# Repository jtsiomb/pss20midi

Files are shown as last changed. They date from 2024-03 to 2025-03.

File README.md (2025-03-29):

YAMAHA PSS-20 MIDI conversion
=============================

About
-----
This is a replacement board for the YAMAHA PSS-20 vintage toy keyboard, which
converts it into a polyphonic MIDI keyboard.

License
-------
Copyright (C) 2024 John Tsiombikas <nuclear@mutantstargoat.com>,
                   Eleni-Maria Stea <elene.mst@gmail.com>

All parts of this project are Free Software/Hardware. Feel free to use, modify
and/or redistribute under the terms of the GNU General Public License v3, or at
your option any later version published by the Free Software Foundation. See
COPYING for details.

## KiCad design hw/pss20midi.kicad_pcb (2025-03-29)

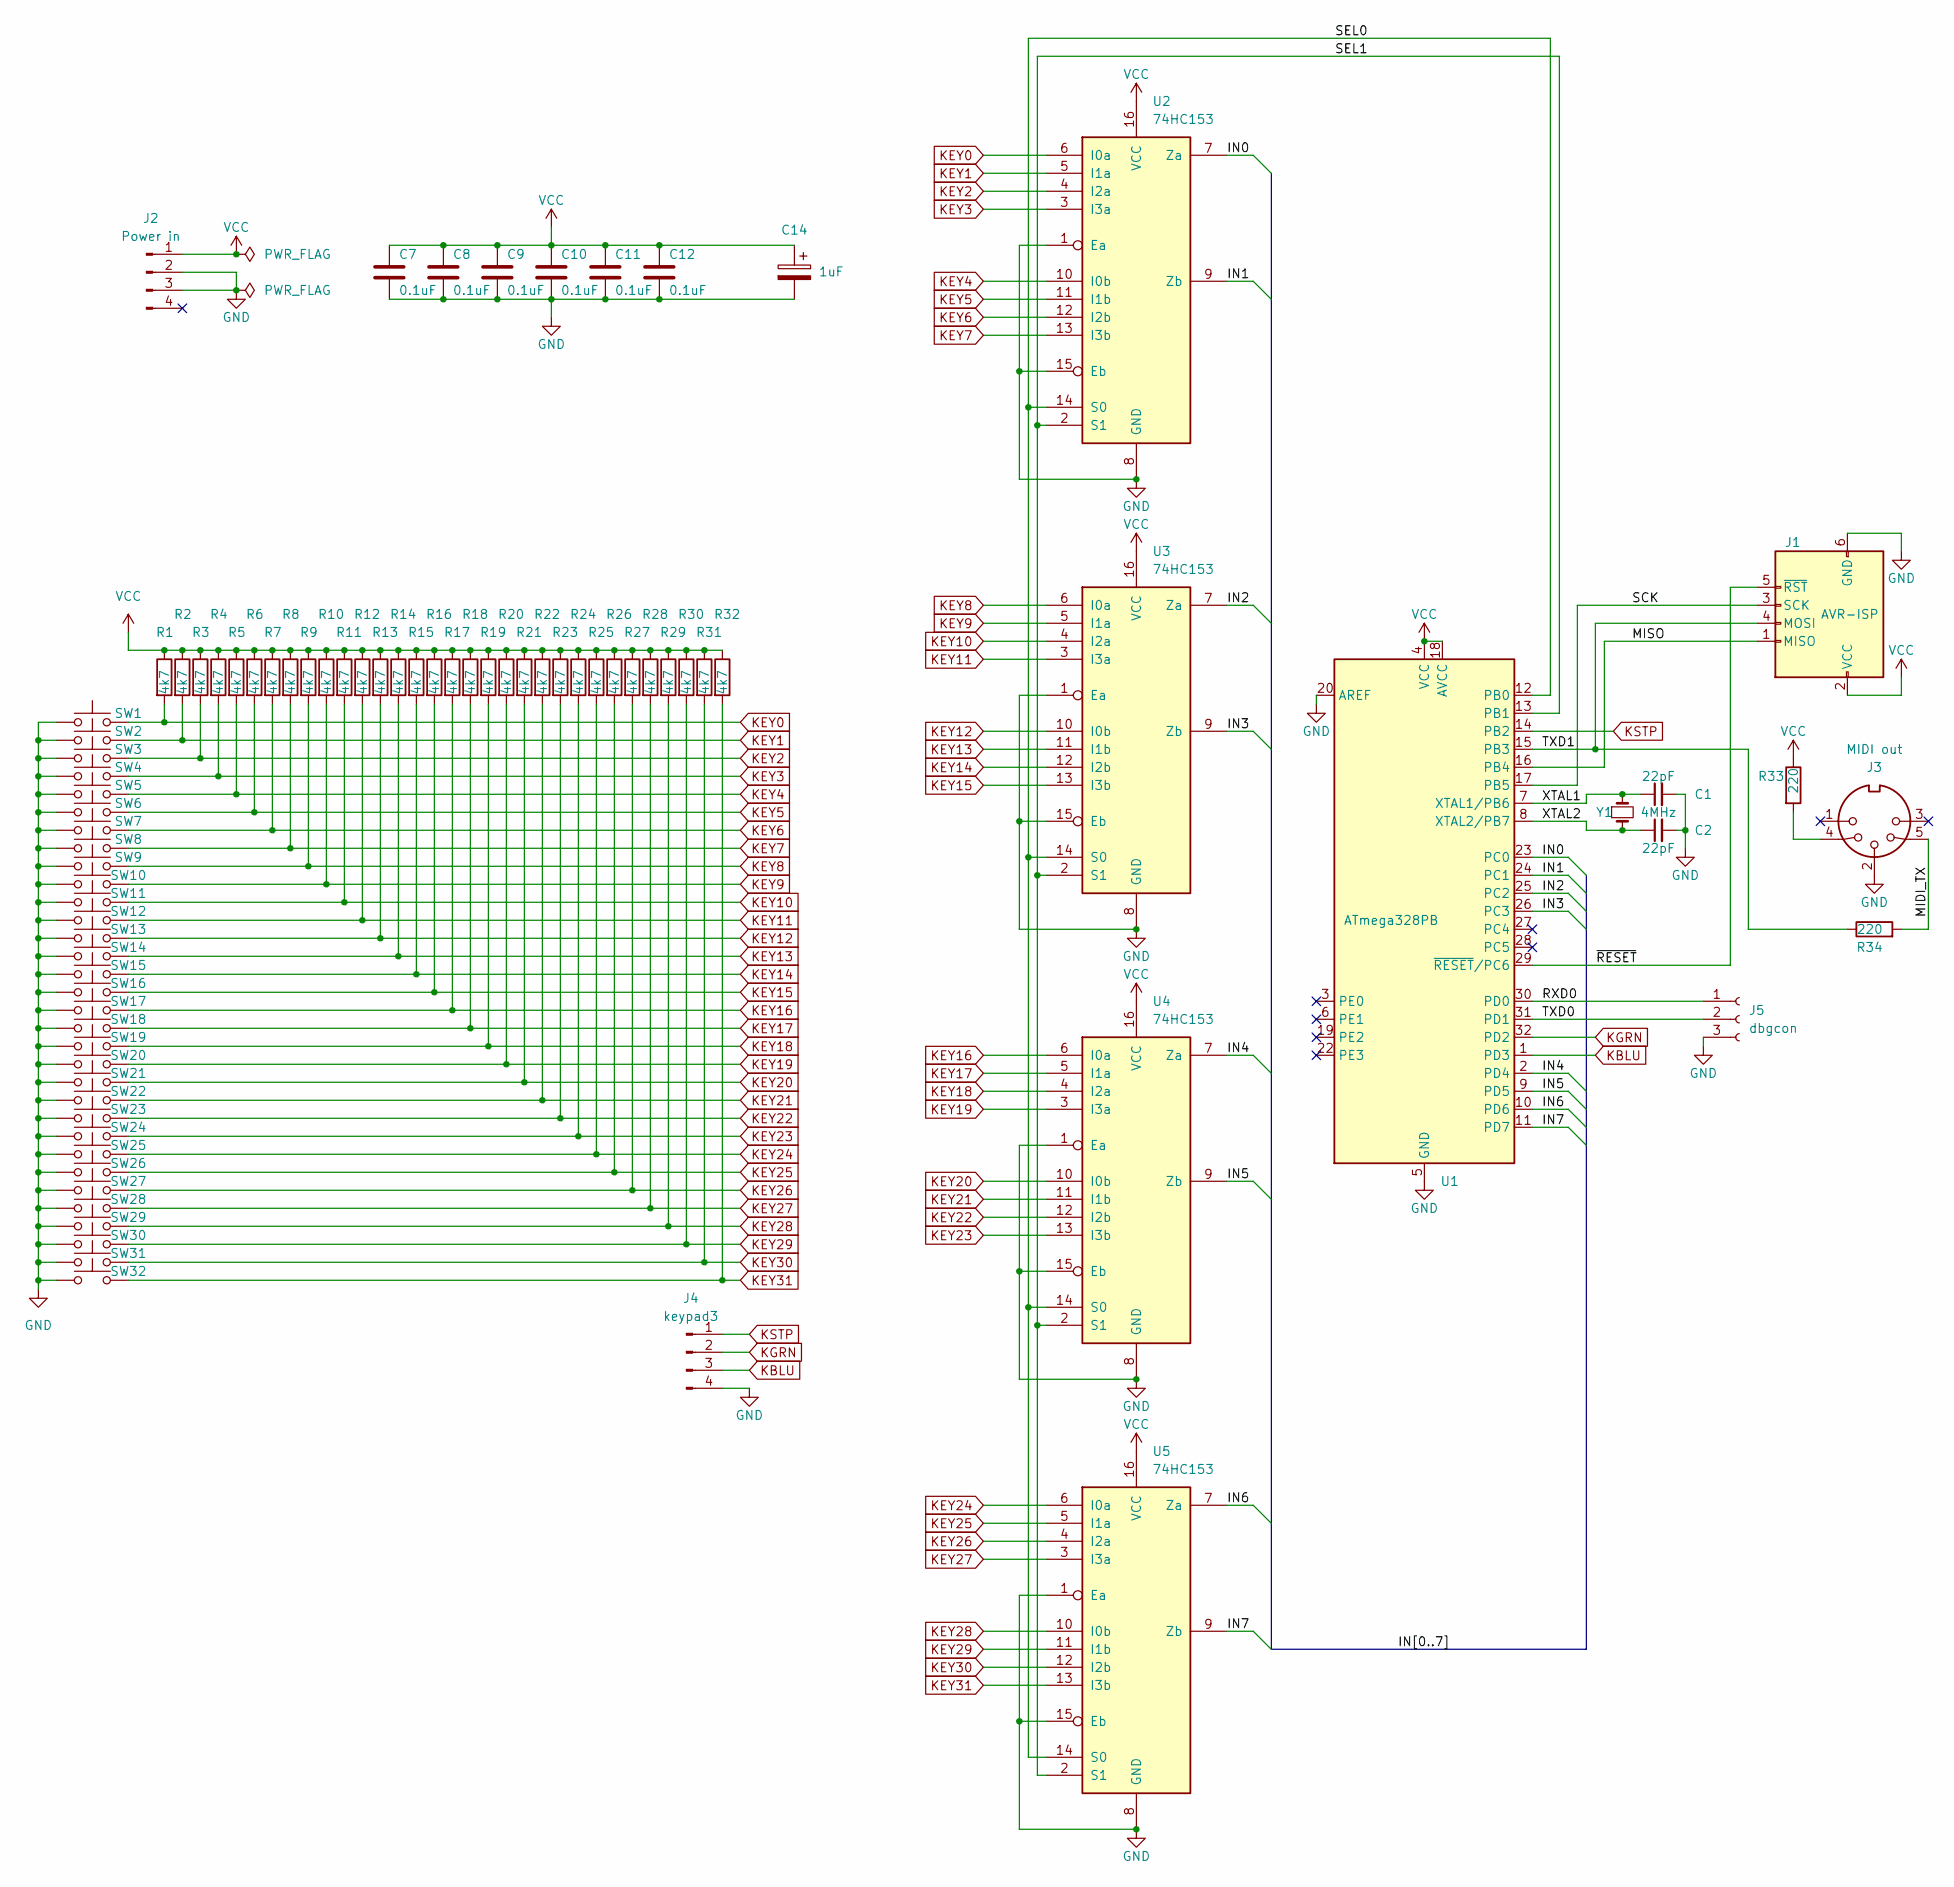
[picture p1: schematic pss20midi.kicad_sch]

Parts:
C1, C2: 22pF; C_0805_2012Metric_Pad1.18x1.45mm_HandSolder
C7, C8, C9, C10, C11, C12: 0.1uF; C_0805_2012Metric_Pad1.18x1.45mm_HandSolder
C14: 1uF; CP_Elec_4x5.4
J1: AVR-ISP; IDC-Header_2x03_P2.54mm_Vertical
J2: Power in; PinHeader_1x04_P2.54mm_Horizontal
J3: MIDI out; PinHeader_1x05_P2.54mm_Horizontal
J4: keypad3; PinHeader_1x04_P2.54mm_Horizontal
J5: dbgcon; PinSocket_1x03_P2.54mm_Horizontal
R1, R2, R3, R4, R5, R6, R7, R8, R9, R10, R11, R12, R13, R14, R15, R16, R17, R18, R19, R20, R21, R22, R23, R24, R25, R26, R27, R28, R29, R30, R31, R32: 4k7; R_0805_2012Metric_Pad1.20x1.40mm_HandSolder
R33, R34: 220; R_0805_2012Metric_Pad1.20x1.40mm_HandSolder
SW1, SW2, SW3, SW4, SW5, SW6, SW7, SW8, SW9, SW10, SW11, SW12, SW13, SW14, SW15, SW16, SW17, SW18, SW19, SW20, SW21, SW22, SW23, SW24, SW25, SW26, SW27, SW28, SW29, SW30, SW31, SW32: SW_Push; bncontact
U1: ATmega328PB; TQFP-32_7x7mm_P0.8mm
U2, U3, U4, U5: 74HC153; SOIC-16_3.9x9.9mm_P1.27mm
Y1: 4MHz; Crystal_SMD_HC49-SD

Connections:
/IN0: U1.23 (PC0), U2.7 (Za)
/IN1: U1.24 (PC1), U2.9 (Zb)
/IN2: U1.25 (PC2), U3.7 (Za)
/IN3: U1.26 (PC3), U3.9 (Zb)
/IN4: U1.2 (PD4), U4.7 (Za)
/IN5: U1.9 (PD5), U4.9 (Zb)
/IN6: U1.10 (PD6), U5.7 (Za)
/IN7: U1.11 (PD7), U5.9 (Zb)
/MIDI_TX: J3.5, R34.2
/MISO: J1.1 (MISO), U1.16 (PB4)
/RXD0: J5.1, U1.30 (PD0)
/SCK: J1.3 (SCK), U1.17 (PB5)
/SEL0: U1.12 (PB0), U2.14 (S0), U3.14 (S0), U4.14 (S0), U5.14 (S0)
/SEL1: U1.13 (PB1), U2.2 (S1), U3.2 (S1), U4.2 (S1), U5.2 (S1)
/TXD0: J5.2, U1.31 (PD1)
/TXD1: J1.4 (MOSI), R34.1, U1.15 (PB3)
/XTAL1: C1.1, U1.7 (XTAL1/PB6), Y1.1
/XTAL2: C2.1, U1.8 (XTAL2/PB7), Y1.2
/~RESET: J1.5 (~RST), U1.29 (~RESET/PC6)
GND: C1.2, C2.2, C7.2, C8.2, C9.2, C10.2, C11.2, C12.2, C14.2, J1.6 (GND), J2.2, J2.3, J3.2, J4.4, J5.3, SW1.1, SW2.1, SW3.1, SW4.1, SW5.1, SW6.1, SW7.1, SW8.1, SW9.1, SW10.1, SW11.1, SW12.1, SW13.1, SW14.1, SW15.1, SW16.1, SW17.1, SW18.1, SW19.1, SW20.1, SW21.1, SW22.1, SW23.1, SW24.1, SW25.1, SW26.1, SW27.1, SW28.1, SW29.1, SW30.1, SW31.1, SW32.1, U1.5 (GND), U1.20 (AREF), U1.21 (GND), U2.1 (Ea), U2.8 (GND), U2.15 (Eb), U3.1 (Ea), U3.8 (GND), U3.15 (Eb), U4.1 (Ea), U4.8 (GND), U4.15 (Eb), U5.1 (Ea), U5.8 (GND), U5.15 (Eb)
KBLU: J4.3, U1.1 (PD3)
KEY0: R1.2, SW1.2, U2.6 (I0a)
KEY1: R2.2, SW2.2, U2.5 (I1a)
KEY2: R3.2, SW3.2, U2.4 (I2a)
KEY3: R4.2, SW4.2, U2.3 (I3a)
KEY4: R5.2, SW5.2, U2.10 (I0b)
KEY5: R6.2, SW6.2, U2.11 (I1b)
KEY6: R7.2, SW7.2, U2.12 (I2b)
KEY7: R8.2, SW8.2, U2.13 (I3b)
KEY8: R9.2, SW9.2, U3.6 (I0a)
KEY9: R10.2, SW10.2, U3.5 (I1a)
KEY10: R11.2, SW11.2, U3.4 (I2a)
KEY11: R12.2, SW12.2, U3.3 (I3a)
KEY12: R13.2, SW13.2, U3.10 (I0b)
KEY13: R14.2, SW14.2, U3.11 (I1b)
KEY14: R15.2, SW15.2, U3.12 (I2b)
KEY15: R16.2, SW16.2, U3.13 (I3b)
KEY16: R17.2, SW17.2, U4.6 (I0a)
KEY17: R18.2, SW18.2, U4.5 (I1a)
KEY18: R19.2, SW19.2, U4.4 (I2a)
KEY19: R20.2, SW20.2, U4.3 (I3a)
KEY20: R21.2, SW21.2, U4.10 (I0b)
KEY21: R22.2, SW22.2, U4.11 (I1b)
KEY22: R23.2, SW23.2, U4.12 (I2b)
KEY23: R24.2, SW24.2, U4.13 (I3b)
KEY24: R25.2, SW25.2, U5.6 (I0a)
KEY25: R26.2, SW26.2, U5.5 (I1a)
KEY26: R27.2, SW27.2, U5.4 (I2a)
KEY27: R28.2, SW28.2, U5.3 (I3a)
KEY28: R29.2, SW29.2, U5.10 (I0b)
KEY29: R30.2, SW30.2, U5.11 (I1b)
KEY30: R31.2, SW31.2, U5.12 (I2b)
KEY31: R32.2, SW32.2, U5.13 (I3b)
KGRN: J4.2, U1.32 (PD2)
KSTP: J4.1, U1.14 (PB2)
unnamed: J3.4, R33.2
VCC: C7.1, C8.1, C9.1, C10.1, C11.1, C12.1, C14.1, J1.2 (VCC), J2.1, R1.1, R2.1, R3.1, R4.1, R5.1, R6.1, R7.1, R8.1, R9.1, R10.1, R11.1, R12.1, R13.1, R14.1, R15.1, R16.1, R17.1, R18.1, R19.1, R20.1, R21.1, R22.1, R23.1, R24.1, R25.1, R26.1, R27.1, R28.1, R29.1, R30.1, R31.1, R32.1, R33.1, U1.4 (VCC), U1.18 (AVCC), U2.16 (VCC), U3.16 (VCC), U4.16 (VCC), U5.16 (VCC)

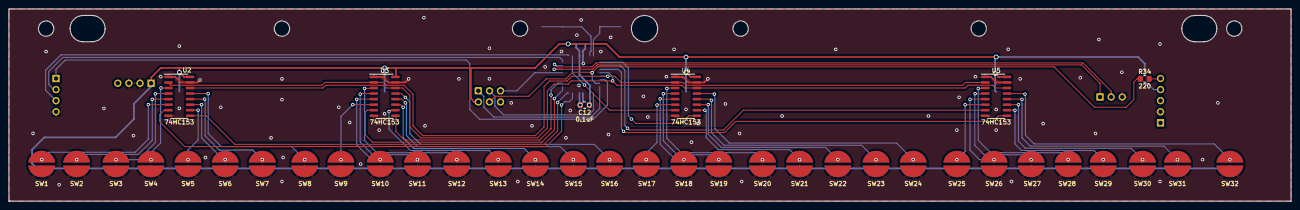
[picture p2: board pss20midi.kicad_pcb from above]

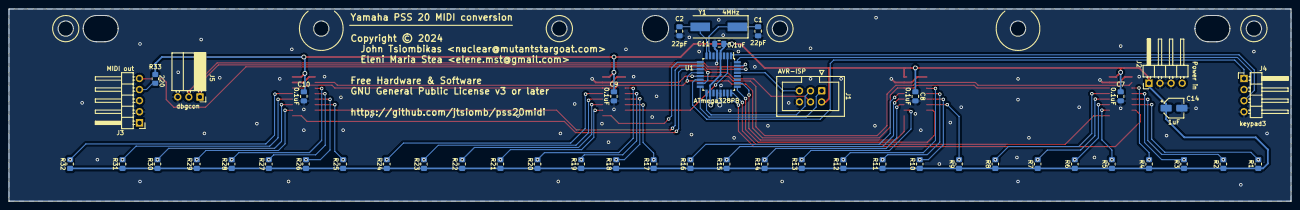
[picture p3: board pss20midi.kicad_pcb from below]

Board: 2 copper layers, 293.5 x 44.0 mm, 86 parts (48 on the bottom side), 57 nets.

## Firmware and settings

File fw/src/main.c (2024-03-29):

#include <stdio.h>
#include <avr/io.h>
#include <stdint.h>
#include "midi.h"
#include "serial.h"

static const int keymap[32] = {
	3, 7, 11, 15, 16, 20, 24, 28,
	0, 4, 8,  12, 17, 21, 25, 29,
	1, 5, 9,  13, 18, 22, 26, 30,
	2, 6, 10, 14, 19, 23, 27, 31,
};
static unsigned char key_state[4]; /* 32 bits for 32 note keys */

static int octave_offs = 60;
static int chan = 0;

#ifdef DBGCON
static int con_send_char(char c, FILE *fp);
static int con_get_char(FILE *fp);

static FILE std_stream = FDEV_SETUP_STREAM(con_send_char, con_get_char, _FDEV_SETUP_RW);
#endif


int main(void)
{
	int i, j, key;
	unsigned char new_state[4], diff_state[4];

	DDRB = 3;
	DDRC = 0;
	DDRD = 0;

#ifdef DBGCON
	init_serial(0, 38400, 8, PAR_NONE, 1);
	stdin = stdout = stderr = &std_stream;
#endif
	init_serial(1, 31250, 8, PAR_NONE, 1);

	for(;;) {
		/* read key state and detect changes */
		for(i=0; i<4; i++) {
			PORTB = i;	/* select mux inputs */
			new_state[i] = ~((PINC & 0xf) | (PIND & 0xf0));
			diff_state[i] = new_state[i] ^ key_state[i];
			key_state[i] = new_state[i];
		}

		for(i=0; i<4; i++) {
			if(diff_state[i] == 0) continue;

			for(j=0; j<8; j++) {
				unsigned char keybit = 1 << j;

				if(diff_state[i] & keybit) {
					/* key changed state */
					key = keymap[(i << 3) + j];
					if(new_state[i] & keybit) {
						/* press */
						midi_note(chan, key + octave_offs, 127);
#ifdef DBGCON
						printf("key %d -> note %d ON\n", key, key + octave_offs);
#endif
					} else {
						/* release */
						midi_note(chan, key + octave_offs, 0);
#ifdef DBGCON
						printf("key %d -> note %d OFF\n", key, key + octave_offs);
#endif
					}
				}
			}
		}
	}

	return 0;
}


#ifdef DBGCON
static int con_send_char(char c, FILE *fp)
{
	if(c == '\n') uart_write(0, '\r');
	uart_write(0, c);
	return 0;
}

static int con_get_char(FILE *fp)
{
	return uart_read(0);
}
#endif

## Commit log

2024-02-22 completed schematic and footprint assignment
    [pss20midi.kicad_sch]
2024-02-26 PCB done
    [pss20midi.kicad_pcb, pss20midi.kicad_sch]
2024-02-26 Added github url to the PCB silkscreen
    [pss20midi.kicad_pcb]
2024-02-26 add gerbers
    [pss20midi-B_Cu.gbr, pss20midi-B_Mask.gbr, pss20midi-B_Paste.gbr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]
2024-03-10 minor code cleanup and debug output on UART0
2024-03-29 fixed MIDI voltage and polarity mistake
    [pss20midi.kicad_pcb, pss20midi.kicad_sch]
2024-03-29 bizarre reordering of they keymap to produce correct notes
    [main.c]
2025-03-29 remove "untested" warning
    [pss20midi.kicad_pcb]

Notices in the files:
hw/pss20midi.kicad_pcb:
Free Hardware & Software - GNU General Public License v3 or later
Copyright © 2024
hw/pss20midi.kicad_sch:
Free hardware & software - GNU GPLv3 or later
